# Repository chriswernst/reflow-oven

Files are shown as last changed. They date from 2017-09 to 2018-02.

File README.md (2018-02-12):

# Reflow Oven
###### June 2017

[//]: # (Image References)

[image1]: ./images/16_2_LCD.jpg
[image2]: ./images/relay_wiring.jpg
[image3]: ./images/arduino_wiring.jpg
[image4]: ./images/bloom_faceplate.jpg
[image5]: ./images/Kester_EP256_Reflow_Profile.png
[image6]: ./images/preheating.jpg
[image7]: ./images/CircuitBoard.jpg
[image8]: ./images/schematic.png
[image9]: ./images/uno_front_2.jpg
[image10]: ./images/bottom_heating.jpg

The goal of this project is to control a two-element toaster oven for reflowing printed circuit boards with surface mount devices.

###
###

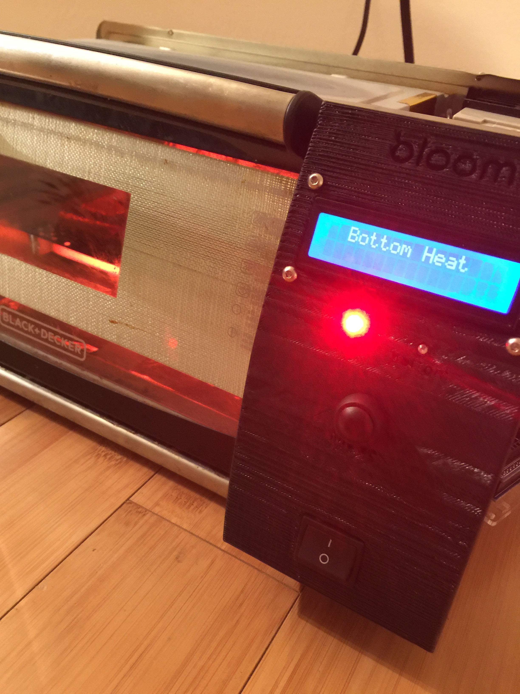
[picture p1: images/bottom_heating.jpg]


###
###

Before we begin, credit  is due to Whizoo.com for his walkthrough of the oven build. If you'd like a prebuilt oven controller, check out the ControlLeo on his site. 

But there's so much more to learn by building it yourself! Check out his [guide that I referenced while building mine.](http://www.whizoo.com/reflowoven)

Mine will be a bit different, as I will not be adding a 3rd "Boost Heating Element". This guide will act as a (hopefully) succint version of his.

###

Let's begin.

###

### Parts List:
1. Toaster Oven
2. K-type thermocouple
3. MAX6675 or similar(for k-type thermocouple)
4. Arduino Uno/Nano/Pro Mini or other similar MCU
5. 16-2 LCD screen
6. Momentary Push Button
7. SPST Switch
8. 2 Solid State Relays (rated for your voltage and amperage - I used 25A, 380VAC/32VDC)
9. 2 3mm LEDs (5mm will work also). I used Blue/Red leds with 3 leads.
10. Heat tape

*(For those doing the math, this comes out to well under $100)*

I used a generic black and decker toaster much like the one below. This toaster already has two heating elements(top and a bottom).

###



###

I used a k-type thermocouple to give us high temperature readings from the oven, and a MAX6675 module to digitize the signal into SPI:



Of course the Arduino Uno (or similiar):


16-2 LCD:



Simple momentary push button(to send interrupts to the Arduino):



Single Pole Single Throw (SPST) Rocker Switch:



Two solid state relays (one for each heating element):



Couple LEDs (color doesn't matter) -  CAD enclosure is designed for 3mm.



Heat tape for sealing up the inside of the toaster oven:



That should do it for parts! Let's get started on the build!

### 
### 

### The Build:

##### Remove Cover metal cover to remove interface knobs

There are many screws around the perimeter, and you'll need to remove these to get access to the backside of the knobs, where we'll house our circuit board and relays.

##### Clean out

You're going to want to start by opening up your oven and giving it a good wipe down. If it has been used, take it outside and shake out the breadcrumbs! On the inside, a Scotch brite pad, or similar, works well to get off any grease or grime.

##### Install thermocouple

From the cavity behind where the knobs were, drill a hole to pass the thermocouple through. Mount it on the back wall of the oven using heattape

##### Tape

Heattape the inside of the oven as well as the inside of the front door(ideally leaving a small window to see the reflow process). Make sure to keep the tape away from the heaters. Do not be shy with the heattape -- it is crucial for holding the heat in and maintaining temperature.

##### Install and Print faceplate

For those using the exact same Black and Decker toaster oven, I have mocked up a face plate in CAD to be printed for the front of the oven to house the electronics.
This can be found in the `3D Models` folder on the repo. My print didn't come out perfect, but it does the job.

###

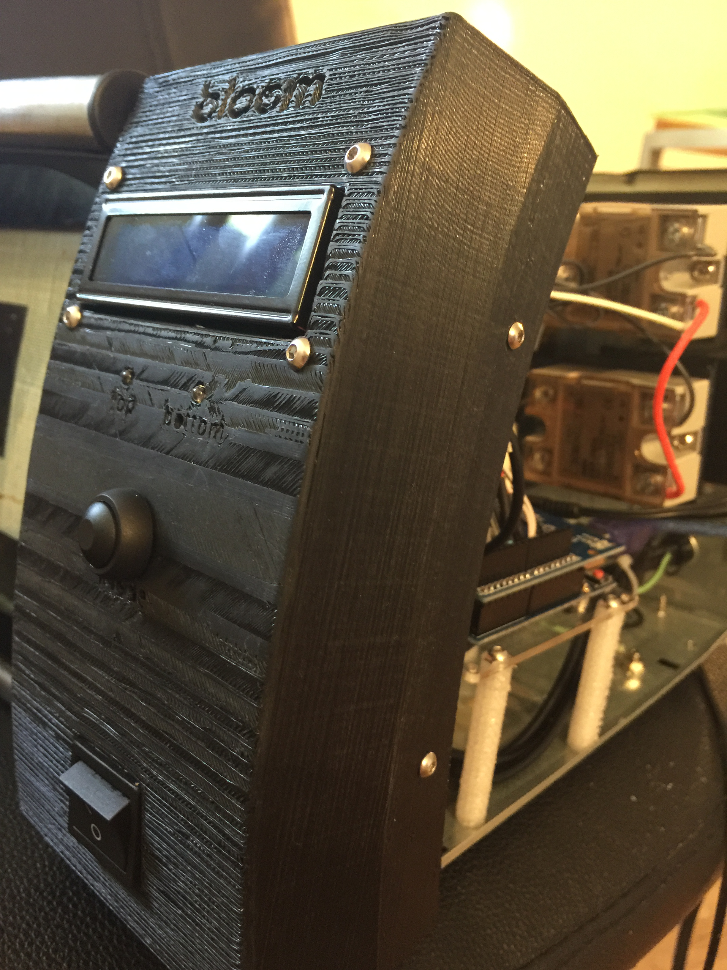
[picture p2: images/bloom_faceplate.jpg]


###

### **README in Progress**

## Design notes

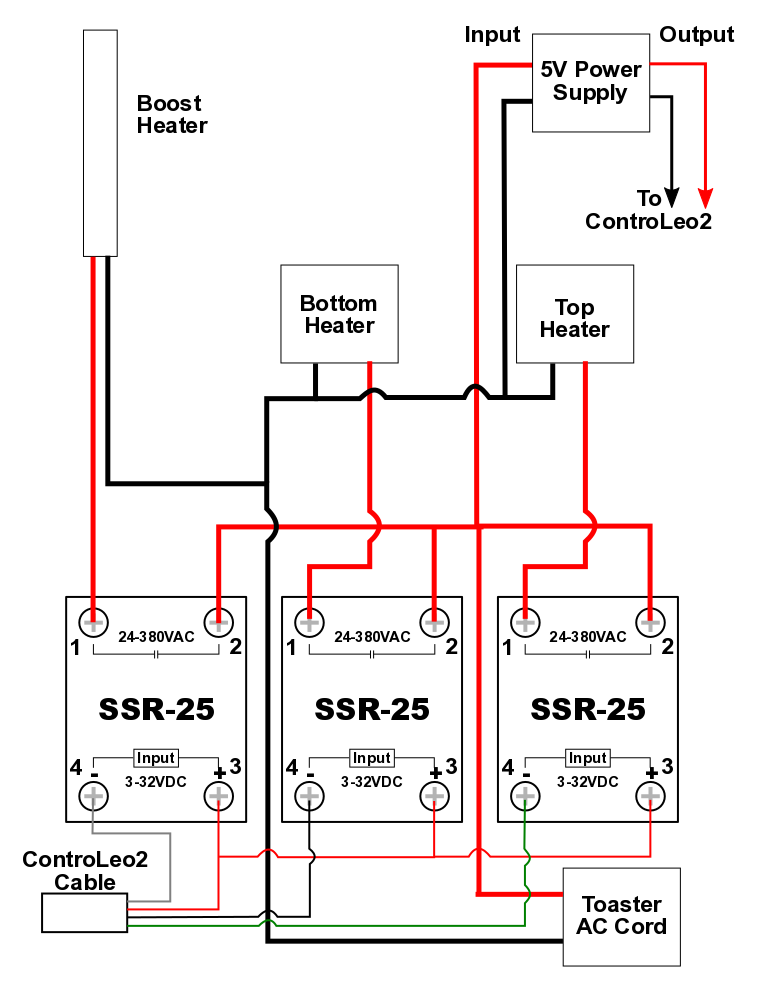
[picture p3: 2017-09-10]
images/schematic.png

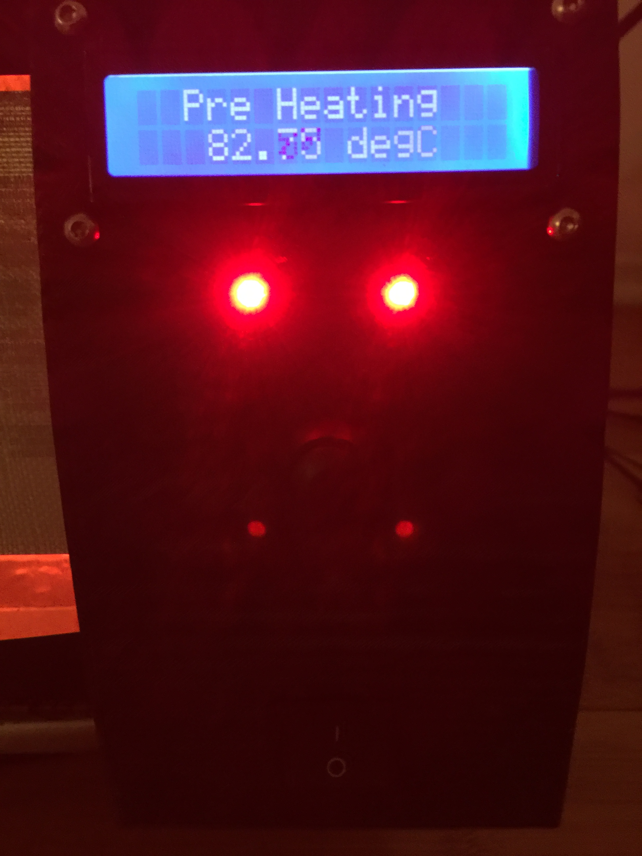
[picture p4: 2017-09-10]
images/preheating.jpg

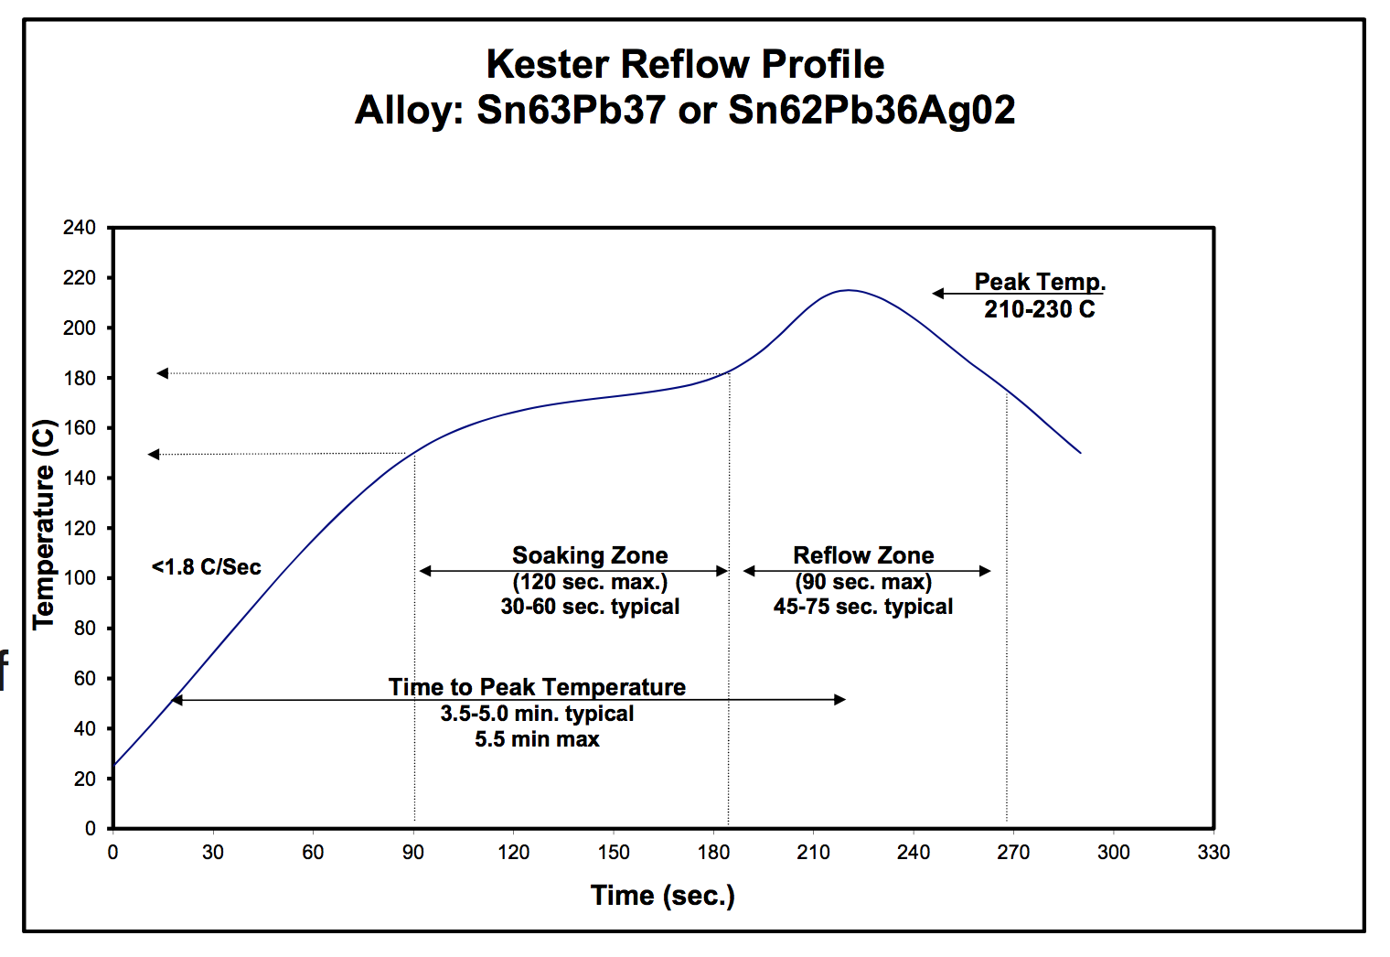
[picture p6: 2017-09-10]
images/Kester_EP256_Reflow_Profile.png

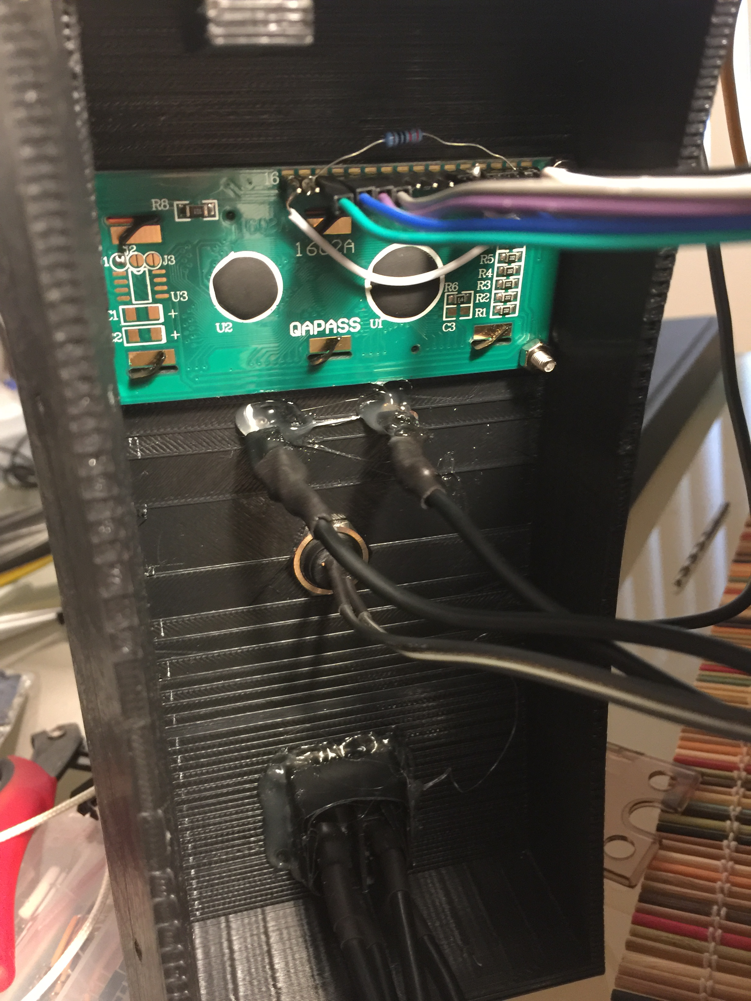
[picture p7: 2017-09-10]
images/16_2_LCD.jpg

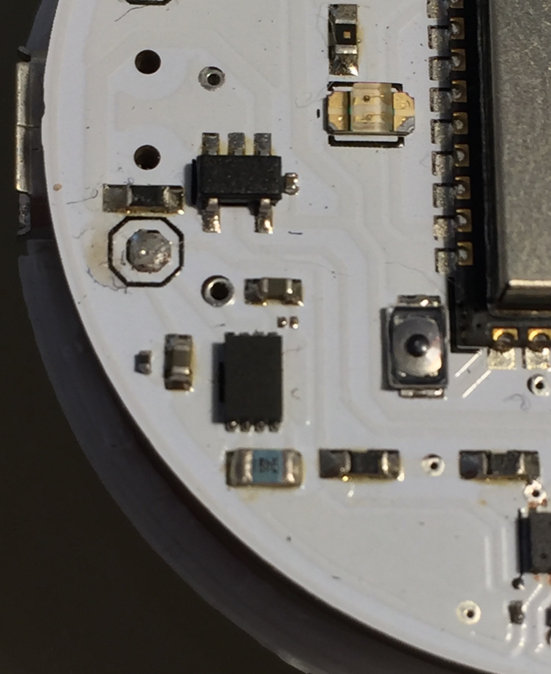
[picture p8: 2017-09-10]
images/CircuitBoard.jpg

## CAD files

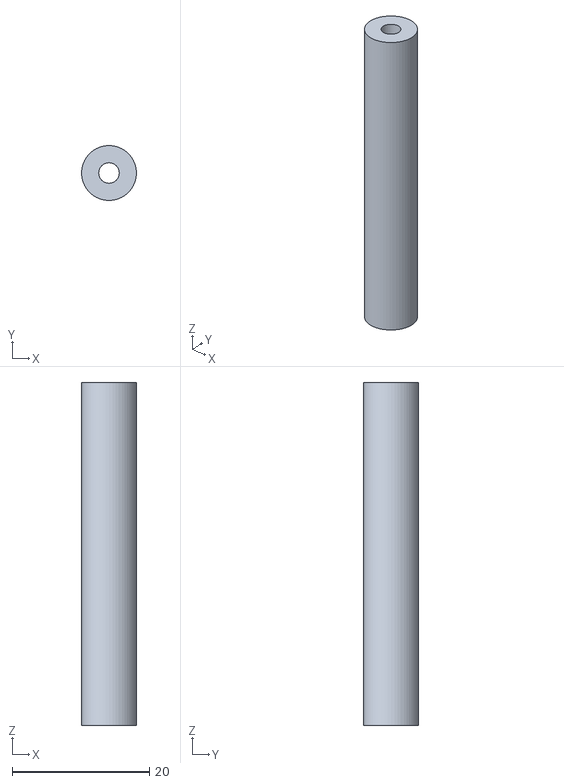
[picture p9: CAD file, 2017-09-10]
3D Models/Arduino_Uno_Legs.stl
8.00 x 8.00 x 50.0

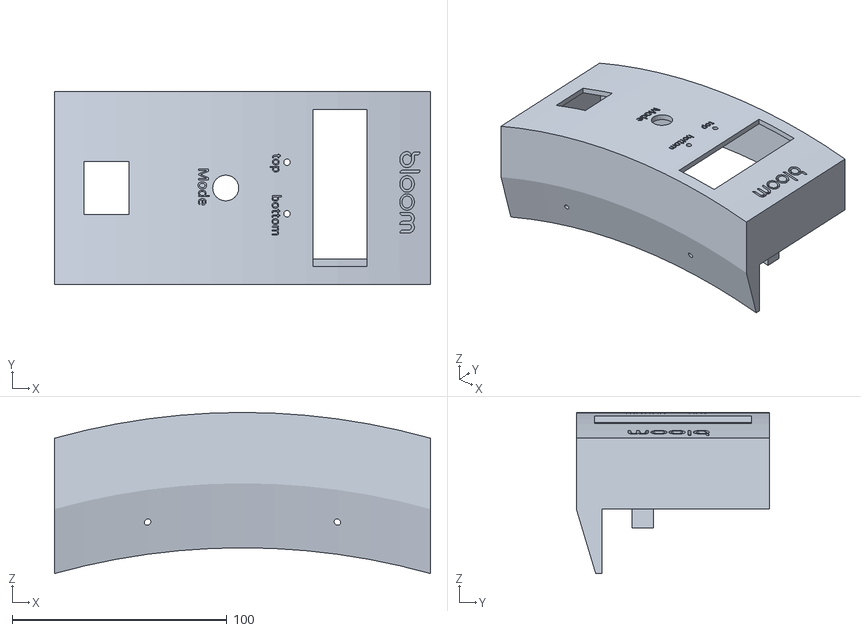
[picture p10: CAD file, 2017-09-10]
3D Models/Reflow_Controller_Enclosure.stl
175.0 x 90.0 x 75.0

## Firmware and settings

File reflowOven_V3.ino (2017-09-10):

/* reflowOven_V3.ino
 * 
 * June 19th, 2017
 * by: Chris Ernst
 * 
 * This sketch is built with the intent of controlling a two-element toaster for reflowing printed circuit boards.
 * 
 * This program is broken into 5 separate steps
 * Some steps will be included in the setup portion of the sketch,
 * while the rest will remain in the loop.
 * 
 * The 5 separate steps are:
 *    1. Startup/Welcome 
 *    2. Preheating Sequence
 *    3. Soaking Process
 *    4. Reflow Process
 *    5. Cooldown/Completion
 *    
 *    
 *    
 * Note: Any numerical values given are in reference to Kester EP256 leaded solder paste.
 * 
 * 
 *
 * In further detail, these steps will complete the following tasks:
 * 
 *    1. Startup/Welcome:  This will give initialize the LCD, I/O pins, and give the user a welcome message.
 *        This will then be followed by a prompt that asks for the 'pushButton' to be pressed to begin preheating.
 *        It will contain a function that sits and waits for the pushButton==1, which will trigger the Preheating sequence.
 *        
 *    2. Preheating Sequence:  This step will heat the oven up to the 'soakStartTemp'. Once the 'soakStartTemp' is acheived,
 *        the oven will hold this temperature and display, via the LCD, "Please load board" in row1, and "Press to Begin" in row 2
 *        and the pushbutton should be pressed to begin the soaking process. (Note: since this is a process with many variables, 
 *        there is no duration specified.)
 *        
 *    3. Soaking Process: Once the pushbutton has been pressed, the oven will begin a 'timer' that will last 'soakDuration' in length
 *        (typically 30-60s, 120s max) and it will attempt to reach the 'reflowStartTemp' in that time period.
 *        
 *    4. Reflow Process:  Once the 'thermocouple.readCelsius()' has exceeded 'reflowStartTemp', the Reflow Process will begin automatically. This 
 *        process will last 'reflowDuration' in length (typically 45-75s; 90s max). This process will complete once 
 *        'thermocouple.readCelsius()' has exceeded 'peakTemperature'. The following condition must be true:'soakingDuration' + 'reflowDuration' = timeToPeak <=330 seconds
 *        
 *    5. Cooldown/Completion:  Once the 'peakTemperature' has been achieved, the cooldown cycle will commence.
 *        If the 'timeToPeak' is greater than 240s, the heaters will turn off completely and the blue lights will flash slowly. 
 *        Once 'timer' is greater than 300s, the blue leds will flash rapidly, and the message will say 'Please Open Door'
 *        
 *        
 *        
 *        
 *                    Kester EP256 Solder Profile     
 * 
 * 
 * 
 * Temperature (Degree Celcius)                 Magic Happens Here!
 * 220-|                                               x  x  
 *     |                                            x        x
 *     |                                         x              x
 *     |                                      x                    x
 * 185-|                                   x                          x
 *     |                              x    |                          |   x   
 *     |                         x         |                          |       x
 *     |                    x              |                          |
 * 150-|               x                   |                          |
 *     |             x |                   |                          |
 *     |           x   |                   |                          | 
 *     |         x     |                   |                          | 
 *     |       x       |                   |                          | 
 *     |     x         |                   |                          |
 *     |   x           |                   |                          |
 * 30 -| x             |                   |                          |
 *     |<     --      >|<    30 - 60 s    >|<       45 - 75 s        >|
 *     | Preheat Stage |   Soaking Stage   |       Reflow Stage       | Cool
 *  0  |_ _ _ _ _ _ _ _|_ _ _ _ _ _ _ _ _ _|_ _ _ _ _ _ _ _ _ _ _ _ _ _ _ _ _ _ 
 *                                                                Time (Seconds)       
 *                                                                
 *         (the above graph was adapted from Whizoo's reflow profile)
 *  
 * 
 * 
 * 
 * 
 *  Variable List
 *  
 *  - buttonPin: The pin the pushbutton is connected to.
 *  - buttonState: the boolean state of the pushbutton.
 *  - counter: A running timer beginning from when the push button is pressed, after the oven has preheated. Timing the total length the board has been in the oven.
 *  - thermocouple.readCelsius(): The current temperature reading of the thermocouple.
 *  - soakStartTemp: This is the temperature the board is placed in at.
 *  - soakDuration: the length of the soak portion of the process.
 *  - reflowStartTemp: This is the temperature the reflow sequence begins at.
 *  - reflowDuration: the length of the reflow portion of the process. 
 *  - peakTemperature: This is the peak temperature the oven will reach; after this, the cooldown will occur.
 *  - timeToPeak = soakingDuration + reflowDuration:  This is the length of time from when the board is placed in the oven until peakTemperature is reached.
 *  - topHeater: the upper heating element of the oven and red led.
 *  - bottomHeater: the lower heating element of the oven and red led.
 *  - blueLeds: the blue anodes of the LEDs in the toaster 
 *  - lcdContrast: this is the pin the contrast is connected to PWM variable on the lcd, which sets the contrast.
 *      Some communication pins:
 *  - thermoCLK: Clock line
 *  - thermoCS: Slave Select
 *  - thermoDO: Master Input Slave Output
 *  
 *  
 *  
 */




  //  Include the relevant libraries
    #include <max6675.h>
    #include <LiquidCrystal.h>
    #include <Wire.h>
    #include <Event.h>
    #include <Timer.h>
    
    Timer t;


  // Pin declarations and initializations:
    int buttonPin = 7;
    int topHeater = 8;
    int bottomHeater = 9;
    int blueLeds = 10;
    int lcdContrast = 6;
    
    // the pins required for the SPI interface from the thermocouple>>MAX6675>>arduino
    int thermoDO = A3;
    int thermoCS = A4;
    int thermoCLK = A5;
    
    MAX6675 thermocouple(thermoCLK, thermoCS, thermoDO);
    int vccPin = 3;
    int gndPin = 2;
    
    // the required pins for the 16x2 LCD
    LiquidCrystal lcd(12, 11, 5, 4, 3, 2);


  // Constant declarations and initializations:
    const int soakStartTemp = 150;
    int soakDuration = 0;
    const int reflowStartTemp = 185;
    int reflowDuration = 0;
    const int peakTemperature = 205;


  // Variable declarations:
    int timeToPeak = soakDuration + reflowDuration;
    int buttonState = 0;
    int currentTemp;
    int printTemp;



void setup() {




  Serial.begin(9600);

  pinMode(vccPin, OUTPUT); 
  digitalWrite(vccPin, HIGH);
  
  pinMode(gndPin, OUTPUT); 
  digitalWrite(gndPin, LOW);

  pinMode(buttonPin, INPUT);

  // Set top heater as output and turn off
  pinMode(topHeater, OUTPUT); 
  digitalWrite(topHeater, LOW);

  // Set bottom heater as output and turn off
  pinMode(bottomHeater, OUTPUT); 
  digitalWrite(bottomHeater, LOW);

  // Turn on the blue leds located on the front of the oven
  pinMode(blueLeds, OUTPUT); 
  analogWrite(blueLeds, 50);

  // Set LCD contrast pin as output, and send 60/255 PWM 24% duty cycle to make text visible
  // It should be noted this value is inconsistent from circuit to circuit and you may have to play with for the text to display properly
  pinMode(lcdContrast, OUTPUT); 
  analogWrite(lcdContrast, 60);

  // Let the LCD warm up
  delay(1000);

  // Initialize the LCD
  lcd.begin(16, 2);

  // Clear the screen
  lcd.clear();
  delay(100);
  
  // This is Step 1. Welcome/Startup

  // Set the cursor and display the Welcome Message
  lcd.setCursor(4, 0);
  lcd.print("Welcome!");
  lcd.noCursor();

  // wait for MAX chip to stabilize
  delay(4000);

  // Clear LCD and display Start
  lcd.clear();


}


void loop() {
  
  // Read the state of the pushbutton
  buttonState = digitalRead(buttonPin);

   
  // Check if the pushbutton is pressed

  if(buttonState == 1) {

    // This is Step 2. Preheating Sequence:

    lcd.clear();
    lcd.setCursor(0, 0);
    lcd.print("Starting Preheat");
    delay(1000);
  
    lcd.clear();
    lcd.setCursor(4, 0);
    lcd.print("Get Ready");
    delay(1000);
  
    lcd.clear();
    lcd.setCursor(5, 0);
    lcd.print("Three");
    delay(500);
  
    lcd.clear();
    lcd.setCursor(6, 0);
    lcd.print("Two");
    delay(500);
  
    lcd.clear();
    lcd.setCursor(6, 0);
    lcd.print("One");
    delay(500);
    
    analogWrite(blueLeds, 0);

    while(thermocouple.readCelsius() < soakStartTemp){
    
      digitalWrite(topHeater, HIGH);
      digitalWrite(bottomHeater, HIGH);
      lcd.clear();
      lcd.setCursor(2, 0);
      lcd.print("Pre Heating");
      lcd.setCursor(3, 1);
      lcd.print(thermocouple.readCelsius());
      Serial.println(thermocouple.readCelsius());
      lcd.print(" degC");
      lcd.noCursor();
      delay(1000);
    }

    delay(50);
    lcd.clear();
    lcd.setCursor(0, 0);
    lcd.print("Hold to Reflow");
    lcd.setCursor(0, 1);
    lcd.print(thermocouple.readCelsius());
    lcd.print(" degC");
    lcd.noCursor();

        
        
    buttonState = digitalRead(buttonPin);
    t.every(10, buttonState);
    
  if(buttonState == 1 && thermocouple.readCelsius() > soakStartTemp){

    // This is Step 3. Soaking Process:

    while(thermocouple.readCelsius() < reflowStartTemp){
      digitalWrite(topHeater, HIGH);
      digitalWrite(bottomHeater, HIGH);
      lcd.clear();
      lcd.setCursor(0, 0);
      lcd.print("Soaking Process");
      lcd.setCursor(0, 1);
      lcd.print(thermocouple.readCelsius());
      Serial.println(thermocouple.readCelsius());
      lcd.print(" degC");
      //lcd.setCursor(13, 1);
      //lcd.print(soakDuration);
      lcd.noCursor();
      delay(1000);
      //soakDuration=soakDuration++; 
    }
    
       // This is Step 4. Reflow Process:
  
    while(thermocouple.readCelsius() < peakTemperature){
      digitalWrite(topHeater, HIGH);
      digitalWrite(bottomHeater, HIGH);
      lcd.clear();
      lcd.setCursor(0, 0);
      lcd.print("Reflowing");
      lcd.setCursor(0, 1);
      lcd.print(thermocouple.readCelsius());
      Serial.println(thermocouple.readCelsius());
      lcd.print(" degC");
      //lcd.setCursor(8, 1);
      //lcd.print(reflowDuration);
      lcd.noCursor();
      delay(1000);
      //reflowDuration=reflowDuration++;
    }
    

    // This is Step 5. Cooldown Process:

    digitalWrite(topHeater, LOW);
    digitalWrite(bottomHeater, LOW);
    lcd.clear();
    lcd.setCursor(0, 0);
    lcd.print("Complete");
    delay(50);
    //lcd.setCursor(0, 1);
    //lcd.print(timeToPeak);
    for(int i=0;i<300;i++){
      analogWrite(blueLeds, 50);
      delay(100);
      analogWrite(blueLeds, 0);
      delay(100);
      Serial.println(thermocouple.readCelsius());

    }
    lcd.noDisplay();      
  }
    
    // hold temp at soakStartTemp
    
    if(thermocouple.readCelsius()<soakStartTemp){
      digitalWrite(topHeater, HIGH);
      digitalWrite(bottomHeater, HIGH);
      }
    else{
      digitalWrite(topHeater, LOW); 
      digitalWrite(bottomHeater, LOW);
      }


  } // initial if button pressed bracket
  else{
    lcd.clear();
    lcd.setCursor(0, 0);
    lcd.print("Press to Preheat");
    lcd.setCursor(3, 1);
    printTemp = lcd.print(thermocouple.readCelsius());
    Serial.println(thermocouple.readCelsius());
    lcd.print(" degC");
    lcd.noCursor();
    delay(500);
  }



} // void loop bracket

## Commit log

2017-09-22 docs: update README.md
    [Arduino_Uno_Legs.stl, Reflow_Controller_Enclosure.stl]
2017-09-22 style: remove redundant directory
    [Arduino_Uno_Legs.stl, Reflow_Controller_Enclosure.stl]
